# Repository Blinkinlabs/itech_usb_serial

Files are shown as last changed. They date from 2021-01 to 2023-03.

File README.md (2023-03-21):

# Itech USB-to-Serial adapter

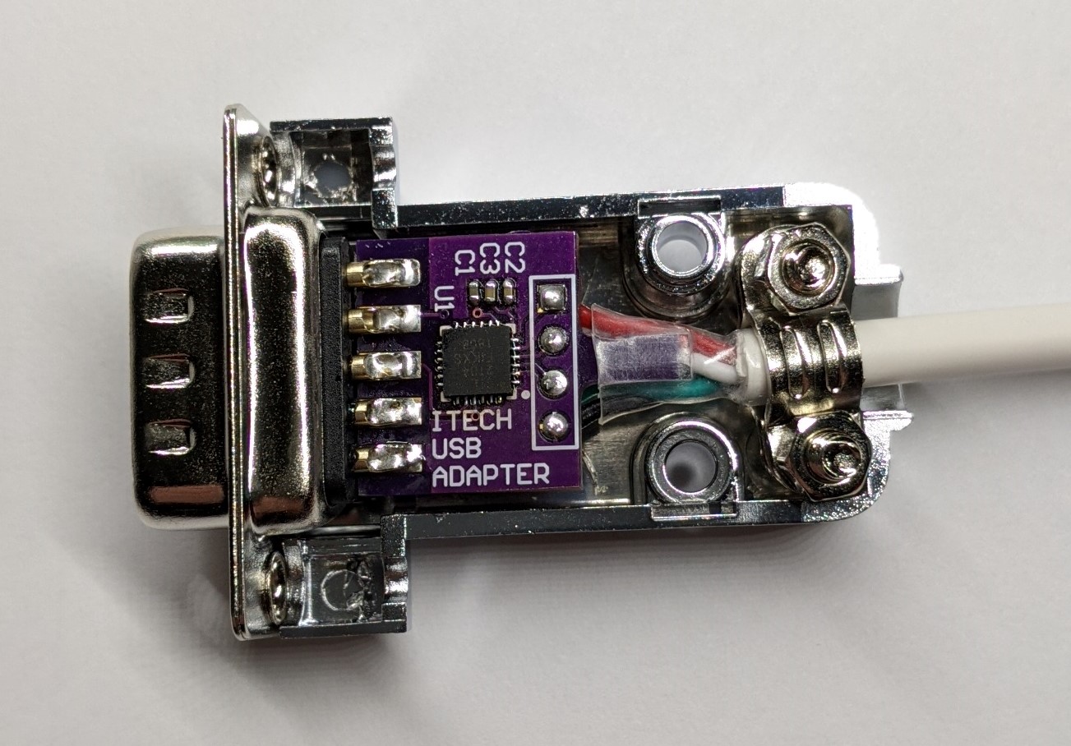
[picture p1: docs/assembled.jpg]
Assembled adapter


Some ITECH test equipment has a DSUB connector with a standard-breaking 5V TTL connector on it. This is a non-isolatd USB converter for this equipment, for interfacing to a PC.

It is known to work with at least the following models:

* ITECH IT6831 DC power supply
* ITECH IT8511 electronic load

It should also work with all models in the [IT6800](http://www.itech.sh/en/product/dc-power-supply/IT6800.html) family, as well as several BK precision devices which they appear to be direct copies of.

Note that the A- and -+ versions of these test equipment generally have built-in USB ports that support USBTMC, which is somewhat easier to work with.

## Making your own

You can order the PCBs direct from the [OSH park project](https://oshpark.com/shared_projects/8jgB7GBf), or use [the gerbers](https://github.com/Blinkinlabs/itech_usb_serial/blob/main/releases/2021-01-06_itech_usb_serial_RevA%20Gerber.zip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) and order from anywhere. You'll need the parts listed in the [BOM](https://github.com/Blinkinlabs/itech_usb_serial/blob/main/releases/2021-01-06_itech_usb_serial_RevA%20BOM.xlsx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), substituting a USB 'A' cable for the 4-pin header. The PCB is designed to be sodlered directly to a [NorComp 171-009-103L001](https://www.digikey.com/short/4c5b7r) DSUB connector, and the whole thing will fit in a [NorComp 977-009-020R121](https://www.digikey.com/short/4c5b3t) shroud.

## Python library

See the [python library readme](https://github.com/Blinkinlabs/itech_usb_serial/blob/main/python/README.md) for a tutorial on using the adapter with Python.

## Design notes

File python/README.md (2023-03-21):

# ITECH serial library for Python

Control ITECH test equipment using a proprietary 26-byte UART protocol.

You'll need to [make your own adapter](https://github.com/blinkinlabs/itech_usb_serial#itech-usb-to-serial-adapter)
to connect your test equipment to your computer, or presumably buy an
isolated one.

Note: If your test equipment has a USB port, use that instead! The -A and -B
variants of some ITECH product lines have an optional USB port, which is
is supported by standard USBTMC libraries such as pyvisa. This library
is intended for devices that only implement a proprietary control protocol
over a TTL serial port.

## Usage

First, install the library from pypi:

    pip install itech_serial

Then, assuming you have an IT8511 load, and it is connected to your computer
using a USB-to-serial converter that was identified as /dev/ttyUSB0, you can
open a connection to it like this:

    from itech_serial import IT8500
    load = IT8500('/dev/ttyUSB0')

During connection, the library will check that the device identify matches a
known string. If you have different equipment  that speaks the same protocol
(such as a BK Precision load), please create an issue on GitHub with the
device details and the reported string.

Once the connection is made, you first need to enable remote control to allow
the device to be controlled over serial:

    load.control_set_remote()

Next, you can set the device to (for example) a 0.5A constant current load:

    load.mode_set('cc')
    load.constant_current_set(0.5)
    load.enable()

You can then read back the measured voltage and current that the load sees:

    print(load.measure)

When you are done, be sure to turn the load off, and (optionally) set the
device control back to local to allow the front panel buttons to work again:

    load.disable()
    load.control_set_local()

## Identifying a specific USB device

If you know what USB to serial converter is connected to your instrument, you
can use the find_usb() function to locate it by VID, PID, and optionally
serial number:

    from itech_serial import find_usb
    load = IT8500(find_usb(vid=0x10c4, pid=0xea60, serial_number='00F84E81')[0])

This is especially helpful for situations where you have multiple instruments
connected to a single computer, and need a reliable way to connect to the
correct one.

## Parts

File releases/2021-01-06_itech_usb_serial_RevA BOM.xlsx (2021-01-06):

Designator | Comment | Manufacturer | PartNumber | Digi-Key Part Number | LCSC PartNumber | Description | Pins | Quantity | Model:Footprint | Case/Package
C1 | 1uF | Murata Electronics North America | GRM155R61A105KE15D | 490-3890-1-ND |  | CAP CER 1UF 10V X5R 0402 | 2 | 1 |  | 0402
C2 | 0.10uF | Murata Electronics North America | GRM152R61A104ME19D | 490-10009-1-ND |  | CAP CER 0.1UF 10V X5R 0402 | 2 | 1 |  | 0402
C3 | 4.7uF | Murata Electronics North America | GRM155R60J475ME47D | 490-5915-1-ND |  | CAP CER 4.7UF 6.3V X5R 0402 | 2 | 1 |  | 0402
J2 | 171-009-103L001 | NorComp Inc. | 171-009-103L001 |  |  | CONN D-SUB PLUG 9POS PNL MNT, side mount DSUB connector | 9 | 1 | CONN D-SUB PLUG 9POS PNL MNT
P1 | Header 4 |  |  |  |  | Header, 4-Pin | 4 | 1 | Connector; Header; 4 Position
U1 | CP2104-F03-GM | Silicon Labs | CP2104-F03-GM |  |  | Single-Chip USB to UART Bridge, 4 Dig I/O Pins, Internal Oscillator, 1024 Bytes EEPROM, -40 to 85 degC, 24-pin QFN | 25 | 1 | QFN, 24-Leads, Body 4x4mm, Pitch 0.5mm, Thermal Pad 2.68x2.68mm, IPC Low Density

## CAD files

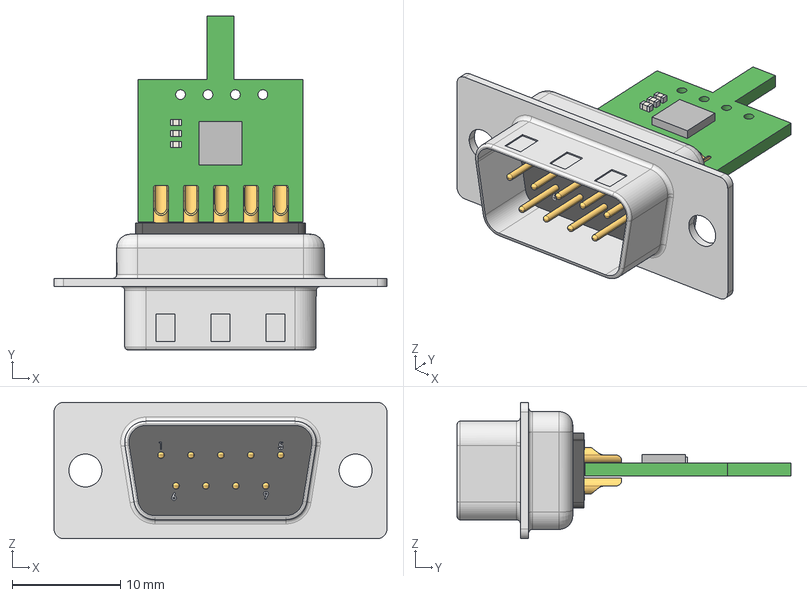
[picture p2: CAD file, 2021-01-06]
releases/2021-01-06_itech_usb_serial_RevA.step
30.8 x 30.9 x 12.6 mm
Extruded x 10

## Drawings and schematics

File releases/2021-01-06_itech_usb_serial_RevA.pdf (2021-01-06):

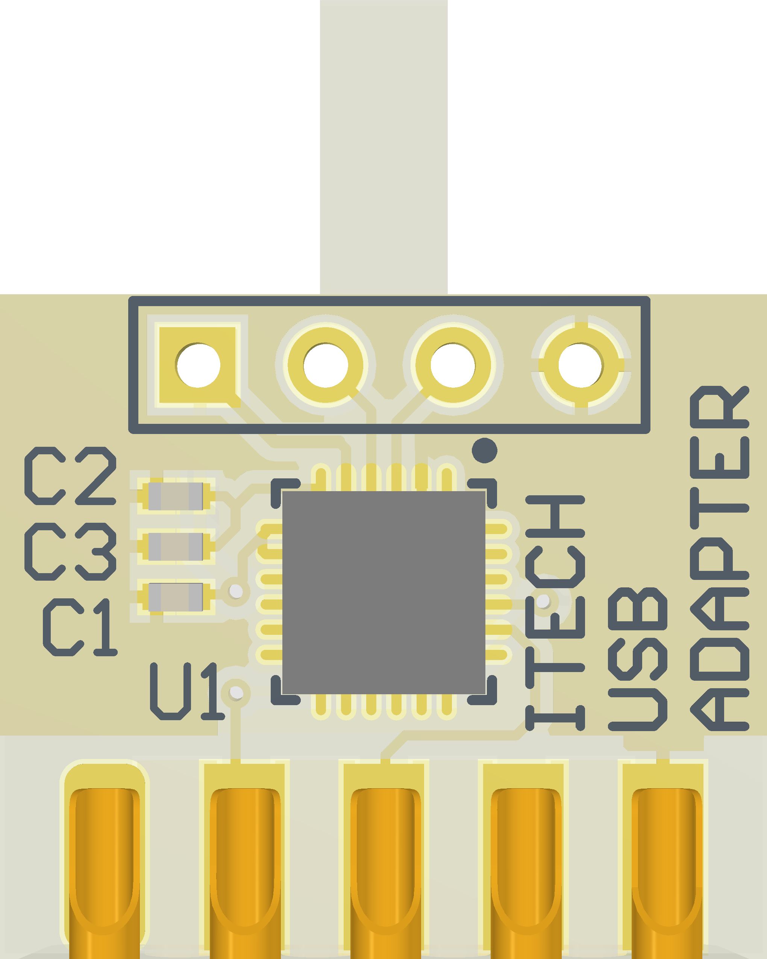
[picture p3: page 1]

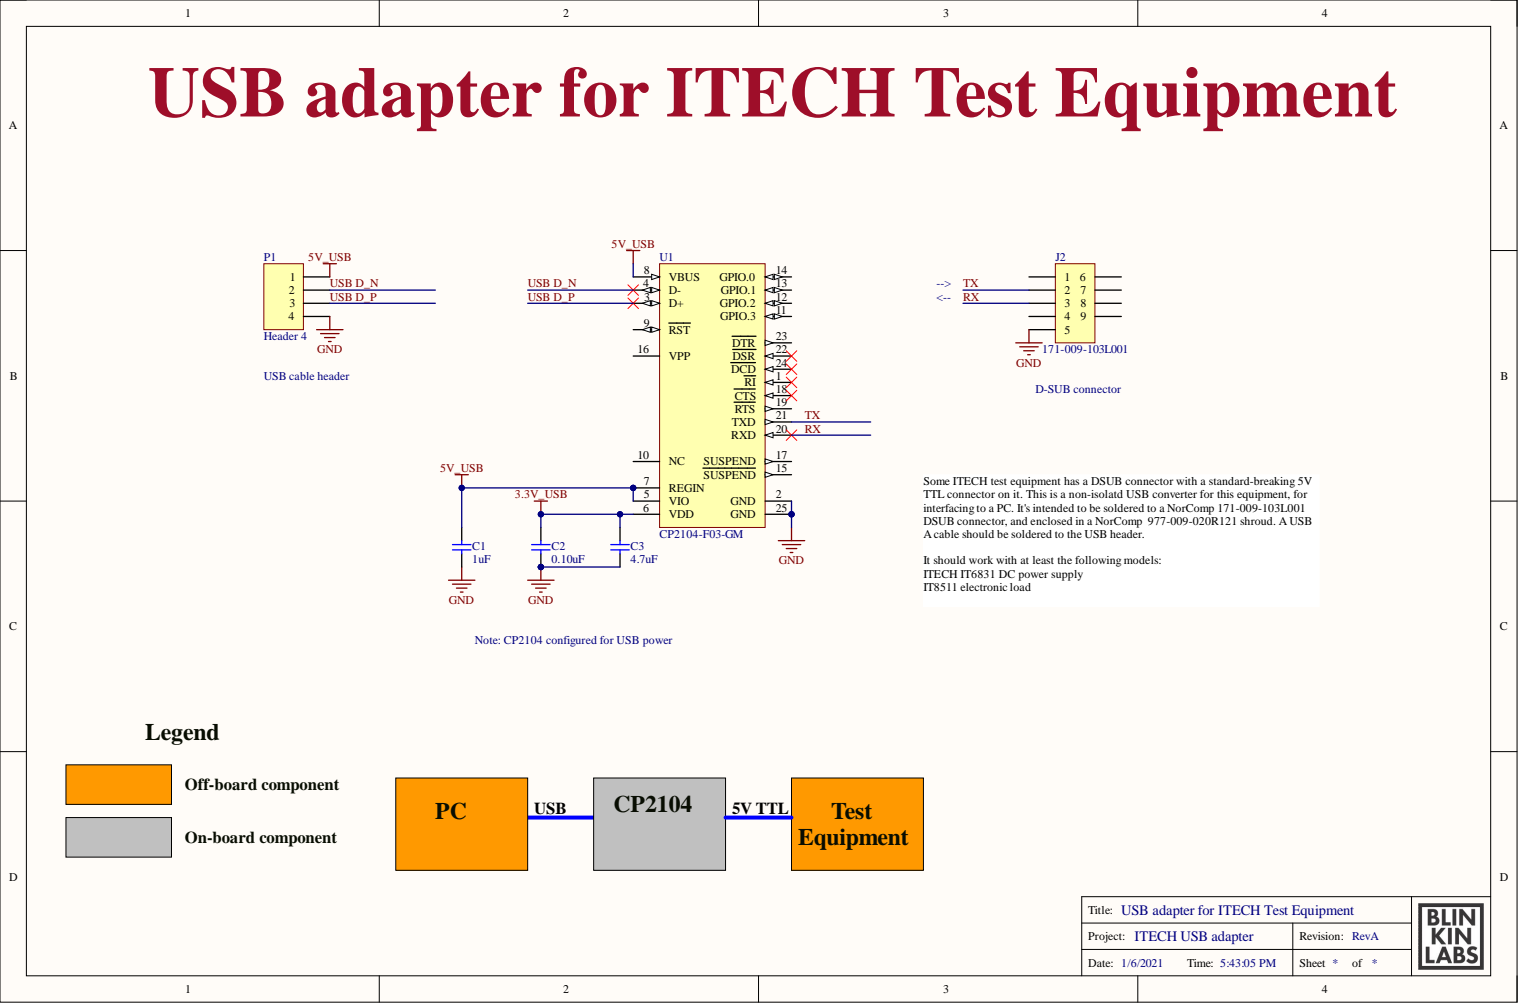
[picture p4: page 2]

USB adapter for ITECH

3.3 V _ USB | 5

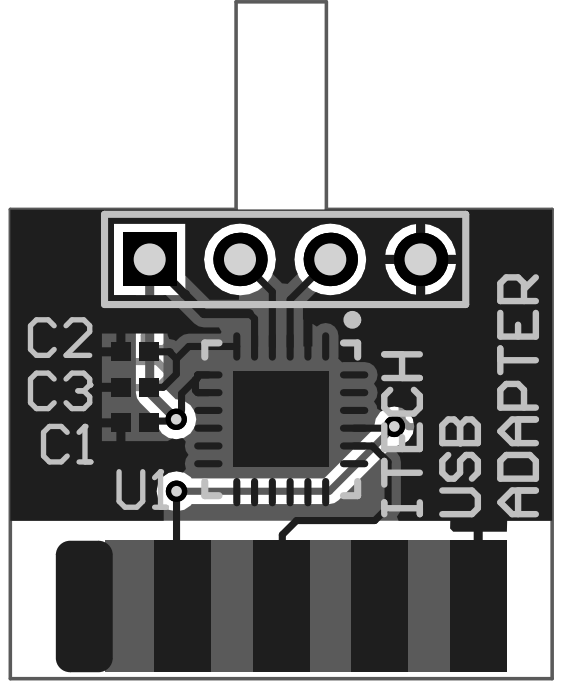
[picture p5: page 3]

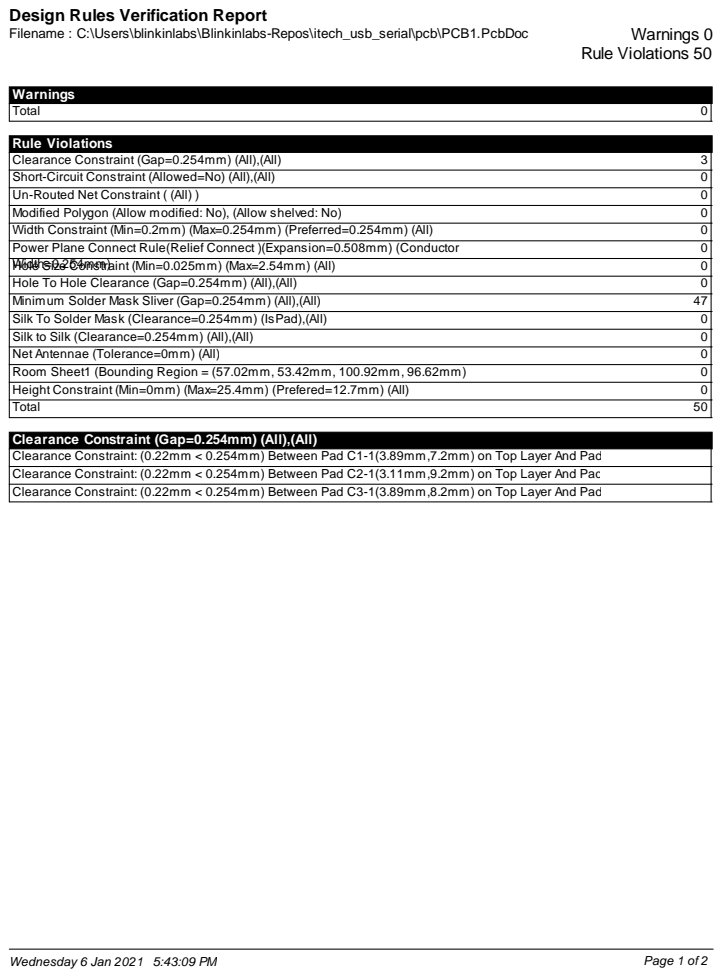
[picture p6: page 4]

Design Rules Verification Report

Rule Violations
Power Plane Connect Rule(Relief Connect )(Expansion=0.508mm) (Conductor
Width=0.254mm)

Clearance Constraint (Gap=0.254mm) (All),(All)
Clearance Constraint: (0.22mm < 0.254mm) Between Pad C1-1(3.89mm,7.2mm) on Top Layer And Pad
Clearance Constraint: (0.22mm < 0.254mm) Between Pad C2-1(3.11mm,9.2mm) on Top Layer And Pad
Clearance Constraint: (0.22mm < 0.254mm) Between Pad C3-1(3.89mm,8.2mm) on Top Layer And Pad

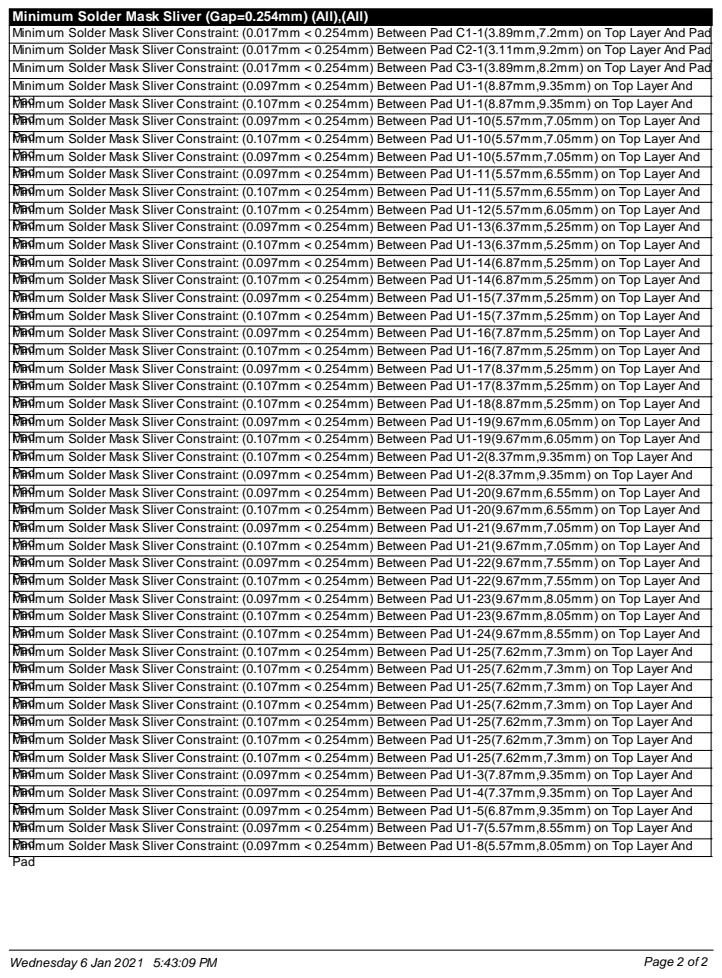
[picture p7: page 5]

Minimum Solder Mask Sliver (Gap=0.254mm) (All),(All)
Minimum Solder Mask Sliver Constraint: (0.017mm < 0.254mm) Between Pad C1-1(3.89mm,7.2mm) on Top Layer And Pad
Minimum Solder Mask Sliver Constraint: (0.017mm < 0.254mm) Between Pad C2-1(3.11mm,9.2mm) on Top Layer And Pad
Minimum Solder Mask Sliver Constraint: (0.017mm < 0.254mm) Between Pad C3-1(3.89mm,8.2mm) on Top Layer And Pad
Minimum Solder Mask Sliver Constraint: (0.097mm < 0.254mm) Between Pad U1-1(8.87mm,9.35mm) on Top Layer And
PaMindimum Solder Mask Sliver Constraint: (0.107mm < 0.254mm) Between Pad U1-1(8.87mm,9.35mm) on Top Layer And
PaMindimum Solder Mask Sliver Constraint: (0.097mm < 0.254mm) Between Pad U1-10(5.57mm,7.05mm) on Top Layer And
PaMindimum Solder Mask Sliver Constraint: (0.107mm < 0.254mm) Between Pad U1-10(5.57mm,7.05mm) on Top Layer And
PaMindimum Solder Mask Sliver Constraint: (0.097mm < 0.254mm) Between Pad U1-11(5.57mm,6.55mm) on Top Layer And
PaMindimum Solder Mask Sliver Constraint: (0.107mm < 0.254mm) Between Pad U1-11(5.57mm,6.55mm) on Top Layer And
PaMindimum Solder Mask Sliver Constraint: (0.107mm < 0.254mm) Between Pad U1-12(5.57mm,6.05mm) on Top Layer And
PaMindimum Solder Mask Sliver Constraint: (0.097mm < 0.254mm) Between Pad U1-13(6.37mm,5.25mm) on Top Layer And
PaMindimum Solder Mask Sliver Constraint: (0.107mm < 0.254mm) Between Pad U1-13(6.37mm,5.25mm) on Top Layer And
PaMindimum Solder Mask Sliver Constraint: (0.097mm < 0.254mm) Between Pad U1-14(6.87mm,5.25mm) on Top Layer And
PaMindimum Solder Mask Sliver Constraint: (0.107mm < 0.254mm) Between Pad U1-14(6.87mm,5.25mm) on Top Layer And
PaMindimum Solder Mask Sliver Constraint: (0.097mm < 0.254mm) Between Pad U1-15(7.37mm,5.25mm) on Top Layer And
PaMindimum Solder Mask Sliver Constraint: (0.107mm < 0.254mm) Between Pad U1-15(7.37mm,5.25mm) on Top Layer And
PaMindimum Solder Mask Sliver Constraint: (0.097mm < 0.254mm) Between Pad U1-16(7.87mm,5.25mm) on Top Layer And
PaMindimum Solder Mask Sliver Constraint: (0.107mm < 0.254mm) Between Pad U1-16(7.87mm,5.25mm) on Top Layer And
PaMindimum Solder Mask Sliver Constraint: (0.097mm < 0.254mm) Between Pad U1-17(8.37mm,5.25mm) on Top Layer And
PaMindimum Solder Mask Sliver Constraint: (0.107mm < 0.254mm) Between Pad U1-17(8.37mm,5.25mm) on Top Layer And
PaMindimum Solder Mask Sliver Constraint: (0.107mm < 0.254mm) Between Pad U1-18(8.87mm,5.25mm) on Top Layer And
PaMindimum Solder Mask Sliver Constraint: (0.097mm < 0.254mm) Between Pad U1-19(9.67mm,6.05mm) on Top Layer And
PaMindimum Solder Mask Sliver Constraint: (0.107mm < 0.254mm) Between Pad U1-19(9.67mm,6.05mm) on Top Layer And
PaMindimum Solder Mask Sliver Constraint: (0.107mm < 0.254mm) Between Pad U1-2(8.37mm,9.35mm) on Top Layer And
PaMindimum Solder Mask Sliver Constraint: (0.097mm < 0.254mm) Between Pad U1-2(8.37mm,9.35mm) on Top Layer And
PaMindimum Solder Mask Sliver Constraint: (0.097mm < 0.254mm) Between Pad U1-20(9.67mm,6.55mm) on Top Layer And
PaMindimum Solder Mask Sliver Constraint: (0.107mm < 0.254mm) Between Pad U1-20(9.67mm,6.55mm) on Top Layer And
PaMindimum Solder Mask Sliver Constraint: (0.097mm < 0.254mm) Between Pad U1-21(9.67mm,7.05mm) on Top Layer And
PaMindimum Solder Mask Sliver Constraint: (0.107mm < 0.254mm) Between Pad U1-21(9.67mm,7.05mm) on Top Layer And
PaMindimum Solder Mask Sliver Constraint: (0.097mm < 0.254mm) Between Pad U1-22(9.67mm,7.55mm) on Top Layer And
PaMindimum Solder Mask Sliver Constraint: (0.107mm < 0.254mm) Between Pad U1-22(9.67mm,7.55mm) on Top Layer And
PaMindimum Solder Mask Sliver Constraint: (0.097mm < 0.254mm) Between Pad U1-23(9.67mm,8.05mm) on Top Layer And
PaMindimum Solder Mask Sliver Constraint: (0.107mm < 0.254mm) Between Pad U1-23(9.67mm,8.05mm) on Top Layer And
PaMindimum Solder Mask Sliver Constraint: (0.107mm < 0.254mm) Between Pad U1-24(9.67mm,8.55mm) on Top Layer And
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

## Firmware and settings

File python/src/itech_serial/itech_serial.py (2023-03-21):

"""
Open Source Initiative OSI - The MIT License:Licensing
Tue, 2006-10-31 04:56 - nelson

The MIT License

Copyright (c) 2009 BK Precision
Copyright (c) 2023 Blinkinlabs

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

import struct
from typing import Any
import serial  # type: ignore
import serial.tools.list_ports  # type: ignore


class InstrumentException(Exception):
    """Instrument exception"""


def find_usb(
        vid: Any = None,
        pid: Any = None,
        serial_number: Any = None) -> list[str]:
    """Find any USB serial device matching the given information"""
    devices = []

    for port in serial.tools.list_ports.comports():
        if vid is not None and port.vid != vid:
            continue
        if pid is not None and port.pid != pid:
            continue
        if serial_number is not None and port.serial_number != serial_number:
            continue

        devices.append(port.device)

    return devices


class _InstrumentInterface:
    """Provides the interface to a 26 byte instrument along with utility
    functions.
    """
    debug = False  # Set to True to see dumps of commands and responses
    PACKET_LENGTH = 26  # Number of bytes in a packet

    def __init__(
            self,
            com_port: str,
            baudrate: int,
            address: int,
            timeout: int = 1):
        """Open a serial connection to the device"""
        self.serial = serial.Serial(com_port, baudrate, timeout=timeout)
        self.address = address

    def dump_command(self, cmd: bytes) -> None:
        """Print out the contents of a 26 byte command.  Example:
            aa .. 20 01 ..   .. .. .. .. ..
            .. .. .. .. ..   .. .. .. .. ..
            .. .. .. .. ..   cb
        """
        print('   ' +
              ' '.join([f"{val:02x}" for val in cmd]).replace('00', '..'))

    def command_properly_formed(self, cmd: bytearray) -> bool:
        """Return True if a command is properly formed; otherwise, return False.
        """
        commands = (
            0x20, 0x21, 0x22, 0x23, 0x24, 0x25, 0x26, 0x27, 0x28, 0x29,
            0x2A, 0x2B, 0x2C, 0x2D, 0x2E, 0x2F, 0x30, 0x31, 0x32, 0x33,
            0x34, 0x35, 0x36, 0x37, 0x38, 0x39, 0x3A, 0x3B, 0x3C, 0x3D,
            0x3E, 0x3F, 0x40, 0x41, 0x42, 0x43, 0x44, 0x45, 0x46, 0x47,
            0x48, 0x49, 0x4A, 0x4B, 0x4C, 0x4D, 0x4E, 0x4F, 0x50, 0x51,
            0x52, 0x53, 0x54, 0x55, 0x56, 0x57, 0x58, 0x59, 0x5A, 0x5B,
            0x5C, 0x5D, 0x5E, 0x5F, 0x60, 0x61, 0x62, 0x63, 0x64, 0x65,
            0x66, 0x67, 0x68, 0x69, 0x6A, 0x6B, 0x6C, 0x12
        )
        # Must be proper length
        if len(cmd) != self.PACKET_LENGTH:
            print("Command length = " + str(len(cmd)) + "-- should be " +
                  str(self.PACKET_LENGTH))
            return False
        # First character must be 0xaa
        if cmd[0] != 0xaa:
            print("First byte should be 0xaa")
            return False
        # Second character (address) must not be 0xff
        if cmd[1] == 0xff:
            print("Second byte cannot be 0xff")
            return False
        # Third character must be valid command
        if cmd[2] not in commands:
            print(f"Third byte not a valid command: {cmd[2]:02x}")
            return False
        # Calculate checksum and validate it
        checksum = self.checksum(cmd)
        if checksum != cmd[-1]:
            print("Incorrect checksum")
            return False
        return True

    def checksum(self, cmd: bytearray) -> int:
        """Return the sum of the bytes in cmd modulo 256.
        """
        checksum = 0
        for i in range(self.PACKET_LENGTH - 1):
            checksum += cmd[i]
        checksum %= 256
        return checksum

    def send_command(self, command: int, payload: bytes = bytes()) -> bytearray:
        """Sends the command to the serial stream and returns the 26 byte
        response.
        """
        cmd = bytearray()
        cmd.append(0xaa)
        cmd.append(self.address)
        cmd.append(command)
        cmd.extend(payload)
        cmd.extend(bytes(self.PACKET_LENGTH - 1 - len(cmd)))
        cmd.append(self.checksum(cmd))

        assert self.command_properly_formed(cmd)

        self.serial.write(cmd)
        response = self.serial.read(self.PACKET_LENGTH)

        if len(response) != self.PACKET_LENGTH:
            raise InstrumentException(
                f"response packet has invalid length: {len(response)}")

#        if response[2] != 0x12:
#            responses = {
#                0x90: "Wrong checksum",
#                0xA0: "Incorrect parameter value",
#                0xB0: "Command cannot be carried out",
#                0xC0: "Invalid command",
#                0x80: "",
#            }
#            raise InstrumentException(
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
